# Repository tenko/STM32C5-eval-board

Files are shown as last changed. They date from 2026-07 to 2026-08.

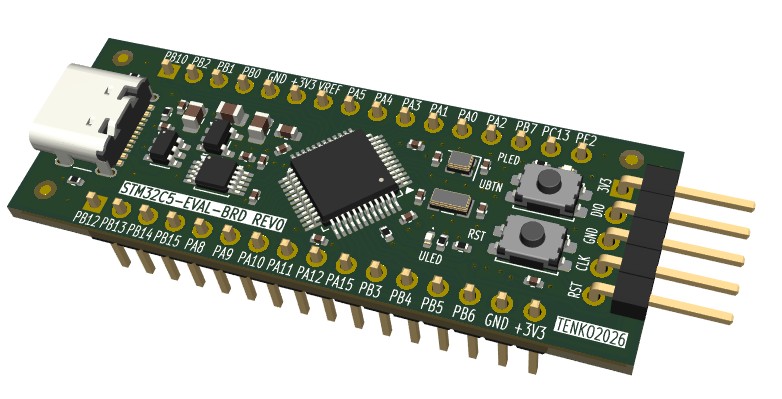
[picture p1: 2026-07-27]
fab/stm32c5-evaluation-board-3d.jpg

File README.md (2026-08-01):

# STM32C5-eval-board

Custom *STM32C5* board in the breadboard friendly *BluePill* format designed in *Kicad v10*.

**Features**

- Compact breadboard friendly board size at 53.5mm x 20mm with 2x16 pin headers.
- STM32C551CE Cortex-M33 MCU, 144 MHz, 512 KB flash, 128 KB RAM. ([Product page](https://www.st.com/en/microcontrollers-microprocessors/stm32c551ce.html) / [Datasheet](https://www.st.com/resource/en/datasheet/stm32c551ce.pdf))
- USB-C power connection with CH340E uart to usb bridge (USART1 used).
- LSE 32768 Hz crystal and HSE with 24 MHz crystal.
- 3V3 LDO with power status led.
- Reset button.
- User led and user button.
- SWD header for programming (Must be used as BOOT0 is not exposed).
- All other MCU pins is routed to board edge headers.

**Note** 

This MCU family is quite new and therefore not all variants of this MCU was available with the usual suppliers
when this board was created. When other variants with *LQFP-48* footprints is available this should be pin compatible
with the layout of this board.

**Pinout** 
stm32c5-evaluation-board-pinout

For complete pin alternative function definitions it is recommended to use the *STMicroelectronics* application *CubeMX2*.

**Production**

Production files adapted to [PCBWay](https://www.pcbway.com/) recommendations is found in the *fab* folder.

**Firmware**

As this is a new MCU family I could only get the *STMicroelectronics* original software
and hardware to work with flashing the device. *SEGGER's J-Link* Debug Probe will also
probably support this MCU family.

In the *firmware* folder there is a project file for *CubeMX2*. By opening this file
it as matter of generate the *CMake* project files.

I used *VSCode* and the *CubeMX* extension to open the generated *CMake* project files and
added the following test code for a simple blinker application:

```C++
/*
  * You can start your application code here
  */

while (1) {
  printf("hello!\n");
  HAL_GPIO_TogglePin(HAL_GPIOB, HAL_GPIO_PIN_9);
  HAL_Delay(2000);
}
```

**Alternative Firmware in Oberon-2**

As an alternative to *C/C++* the [ECSOberon](https://ecs.openbrace.org/) language and the
[ECSMicroLib](https://github.com/tenko/ECSMicroLib/) framework can be used to develop
firmware for this board.

*ECSOberon* has a number of benefits for MCU applications:

- Simplest possible language (the [language report](https://github.com/OberonSystem3/TheOberonCompanionCD/blob/main/Papers/Oberon2.pdf?raw=true) is 20 pages), yet supporting 
  object oriented design with single inheritance.
- The language has the bit *SET* type which makes fiddling with bit register of the *MCU* very easy and natural.
- The *ECSOberon* language is updated with manual allocation, unsigned types, variable pointers, packages and simple templates.
  Making the language more practical for system programming and *MCUs* than the original *Oberon-2* implementation.
- No header files to worry about. The visibility of the code elements is defined directly in the module.
- The module and package concept keeps the code cleanly segregated and avoid the problem with colliding names in *C*.
- The [documentation](https://ecs.openbrace.org/manual/) is excellent and reported bugs is fixed quickly.

The drawbacks of *ECSOberon*:

- *Oberon-2* is a verbose language and require upper case keyword.
  However with an *IDE* and auto-completion this is a minor issue in my opinion.
- No support for a pre-processor. Some cases can be solved with help of templates, but otherwise
  this must be solved with shell scripts.
  However this omission keeps the code base readable in my opinion.
- Not much existing code exists and many things must be implemented from scratch.
  Code from the original [OberonSystem 3](https://github.com/OberonSystem3) or from [BlackBox Component Builder](https://blackbox.oberon.org/) could be reused.
  
  This is the major drawback in my opinion.

**Testing**

[board-testing.webm](https://github.com/user-attachments/assets/a6211ade-eac5-4887-8b39-223c8f42b538)

The board has been verified to work correctly with the uart-to-usb bridge, leds, buttons and crystals.

Minor issues:

- The *SWDIO* and *SWDCLK* pin was swapped.
- The silkscreen was difficult to read.

This will be fixed in a future revision along with any other issue.

**TODO** 

- Fix *SWD CLK/DIO* swap on silkscreen and schematic.
- Possible expose *BOOT0* with a test point on PCB.
- Possible add PCB jumper to disconnect power led for battery operations.
- Review pins used for user button/led and usb-to-uart.

**Sponsors** 

This board was generously sponsored by [PCBWay](https://www.pcbway.com/) and this project was handled
in quick and professional way in my experience. Thanks.

**Acknowledgments**

This board was developed and with help of and inspiration by the excellent instruction videos on the [Phil's Lab](https://www.youtube.com/@PhilsLab)
Youtube channel.

Also initially skeptical to *KiCAD* software, it turned out to be a very nice experience working with this application.
The team behind *KiCAD* does an excellent job in turning this application into a professional tool.

## License
This project is licensed under the MIT License - see the LICENSE file for details.

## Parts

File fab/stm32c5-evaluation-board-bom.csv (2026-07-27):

Item # | Designator | Qty | Manufacturer | Mfg Part # | Description | Value | Footprint | Datasheet | Distributor Link 1 | Distributor Link 2
1 | C1,C2,C4,C6,C7,C8,C10,C11,C13,C14 | 10 | Murata Electronics | GRM155R71E104KE14D | Unpolarized capacitor MLCC X7R | 100n | Capacitor_SMD:C_0402_1005Metric | https://search.murata.co.jp/Ceramy/image/img/A01X/G101/ENG/GRM155R71E104KE14-01.pdf | https://eu.mouser.com/ProductDetail/Murata-Electronics/GRM155R71E104KE14D?qs=IPQhFcwEUOgaz7Co1ZLU6w%3D%3D | https://www.digikey.com/en/products/detail/murata-electronics/GRM155R71E104KE14D/4905173
2 | C3,C5,C9 | 3 | Murata Electronics | GRM21BZ71E475KE15L | Unpolarized capacitor MLCC X7R | 4u7 | Capacitor_SMD:C_0805_2012Metric | https://search.murata.co.jp/Ceramy/image/img/A01X/G101/ENG/GRM21BZ71E475KE15-01.pdf | https://eu.mouser.com/ProductDetail/Murata-Electronics/GRM21BZ71E475KE15L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 | https://www.digikey.com/en/products/detail/murata-electronics/GRM21BZ71E475KE15L/13904861
3 | C12 | 1 | Murata Electronics | GRM188Z71E225KE43D | Unpolarized capacitor MLCC X7R | 2u2 | Capacitor_SMD:C_0603_1608Metric | https://pim.murata.com/asset/pim4/ceramicCapacitorSMD/GRM188Z71E225KE43-01A-EN_PDF_CERAMICCAPACITORSMD | https://eu.mouser.com/ProductDetail/Murata-Electronics/GRM188Z71E225KE43D?qs=Ey7%2FXF42M3cRXEZQV5QZIQ%3D%3D | https://www.digikey.com/en/products/detail/murata-electronics/GRM188Z71E225KE43D/16602147
4 | C15,C16 | 2 | Murata Electronics | GCM1555C1H6R0BA16D | Unpolarized capacitor MLCC NP0 | 6p | Capacitor_SMD:C_0402_1005Metric | https://eu.mouser.com/datasheet/3/76/3/GCM1555C1H6R0BA16_01A.pdf | https://eu.mouser.com/ProductDetail/Murata-Electronics/GCM1555C1H6R0BA16D?qs=QzBtWTOodeXySBgacy71QA%3D%3D | https://www.digikey.com/en/products/detail/murata-electronics/GCM1555C1H6R0BA16D/11618627
5 | C17,C18 | 2 | Murata Electronics | GCM1555C1H200FA16D | Unpolarized capacitor MLCC NP0 | 20p | Capacitor_SMD:C_0402_1005Metric | https://pim.murata.com/asset/pim4/ceramicCapacitorSMD/GCM1555C1H200FA16-01A-EN_PDF_CERAMICCAPACITORSMD | https://eu.mouser.com/ProductDetail/Murata-Electronics/GCM1555C1H200FA16D?qs=QzBtWTOodeWP0i4OUEdl4Q%3D%3D | https://www.digikey.com/en/products/detail/murata-electronics/GCM1555C1H200FA16D/13401847
6 | D1 | 1 | STMicroelectronics | USBLC6-2SC6 | Very low capacitance ESD protection diode, 2 data-line, SOT-23-6 | USBLC6-2SC6 | Package_TO_SOT_SMD:SOT-23-6 | https://www.st.com/resource/en/datasheet/usblc6-2.pdf | https://www.digikey.com/en/products/detail/stmicroelectronics/USBLC6-2SC6/1040559 | https://eu.mouser.com/ProductDetail/STMicroelectronics/USBLC6-2SC6?qs=po45yt2pPpu%2FhNIlwQdTlg%3D%3D
7 | D2 | 1 | Wurth Elektronik | 150040VS73240 | Light emitting diode green | GR | LED_SMD:LED_0402_1005Metric | https://www.we-online.com/components/products/datasheet/150040VS73240.pdf | https://eu.mouser.com/ProductDetail/Wurth-Elektronik/150040VS73240?qs=8Aam6%252B7C6HEhyesRm%252BQyFQ%3D%3D | https://www.digikey.com/en/products/detail/w%C3%BCrth-elektronik/150040VS73240/8557157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
8 | D3 | 1 | Wurth Elektronik | 150040RS73240 | Light emitting diode | RD | LED_SMD:LED_0402_1005Metric | https://www.we-online.com/components/products/datasheet/150040RS73240.pdf | https://eu.mouser.com/ProductDetail/Wurth-Elektronik/150040RS73240?qs=8Aam6%252B7C6HGMiInmnlrBiw%3D%3D | https://www.digikey.com/en/products/detail/w%C3%BCrth-elektronik/150040RS73240/8557156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
9 | J1 | 1 | Global Connector Technology | USB4105-GF-A-120 | USB 2.0-only 16P Type-C Receptacle connector | USB4105-GF-A | Connector_USB:USB_C_Receptacle_GCT_USB4105-xx-A_16P_TopMnt_Horizontal | https://www.mouser.com/catalog/specsheets/Global_Connector_Technology_usb4105.pdf | https://eu.mouser.com/ProductDetail/GCT/USB4105-GF-A-120?qs=QNEnbhJQKva%252Bjxw%2FpEjDhQ%3D%3D | https://www.digikey.com/en/products/detail/gct/USB4105-GF-A-120/14559037
10 | R1,R2 | 2 | YAGEO | RC0402FR-075K1L | Resistor | 5k1 | Resistor_SMD:R_0402_1005Metric | https://www.mouser.com/catalog/specsheets/YAGEO_PYu_RC_Group_51_RoHS_L_12.pdf | https://eu.mouser.com/ProductDetail/YAGEO/RC0402FR-075K1L?qs=YUgVZYePFqCSmQuaha43RA%3D%3D | https://www.digikey.com/en/products/detail/yageo/RC0402FR-075K1L/726624
11 | R3 | 1 | YAGEO | RC0402FR-070RL | Resistor | 0R | Resistor_SMD:R_0402_1005Metric | https://www.mouser.com/catalog/specsheets/YAGEO_PYu_RC_Group_51_RoHS_L_12.pdf | https://eu.mouser.com/ProductDetail/YAGEO/RC0402FR-070RL?qs=sxZXDnvRBEhfSy4CZGX2ww%3D%3D | https://www.digikey.com/en/products/detail/yageo/RC0402FR-070RL/2827570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
12 | R4,R8 | 2 | YAGEO | RC0402FR-07220RL | Resistor | 220R | Resistor_SMD:R_0402_1005Metric | https://www.mouser.com/catalog/specsheets/YAGEO_PYu_RC_Group_51_RoHS_L_12.pdf | https://eu.mouser.com/ProductDetail/YAGEO/RC0402FR-07220RL?qs=UOUeRUa%252B8Wkw9iNOZEwgHw%3D%3D | https://www.digikey.com/en/products/detail/yageo/RC0402FR-07220RL/726565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
13 | R5,R6 | 2 | YAGEO | RC0402FR-0710KL | Resistor | 10k | Resistor_SMD:R_0402_1005Metric | https://www.mouser.com/catalog/specsheets/YAGEO_PYu_RC_Group_51_RoHS_L_12.pdf | https://eu.mouser.com/ProductDetail/YAGEO/RC0402FR-0710KL?qs=I1mnnYJTTsxUoNwrUsQExA%3D%3D | https://www.digikey.com/en/products/detail/yageo/RC0402FR-0710KL/726523
14 | SW1,SW2 | 2 | Panasonic | EVQ-P2K02Q | Tactile Switches NO SPST 4.7mm x 3.5mm | EVQ-P2K02Q | Button_Switch_SMD:SW_SPST_EVQP2_MiddlePushTravel_H2.5mm | https://4donline.ihs.com/images/VipMasterIC/IC/PANA/PANAS38695/PANAS38695-1.pdf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 | https://eu.mouser.com/ProductDetail/Panasonic/EVQ-P2K02Q?qs=whhzBCqEXCsdBl5GlK3V%252BA%3D%3D | https://www.digikey.com/en/products/detail/panasonic-industry/EVQ-P2K02Q/304155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
15 | U1 | 1 | MaxLinear, Inc. | SPX3819M5-L-3-3 | 500mA Low drop-out regulator, Fixed Output 3.3V, SOT-23-5 | SPX3819M5-L-3-3 | Package_TO_SOT_SMD:SOT-23-5 | https://www.maxlinear.com/Document/index?id=22106&languageid=1033&type=Data%20Sheets&partnumber=SPX3819 | https://www.digikey.com/en/products/detail/maxlinear-inc/SPX3819M5-L-3-3/2411180 | https://eu.mouser.com/ProductDetail/MaxLinear/SPX3819M5-L-3-3-TR?qs=S%2FCBhQS5rCp1Bb7a%252BD%2FCBQ%3D%3D
16 | U2 | 1 | WCH | CH340E | USB serial converter, UART, MSOP-10 | CH340E | Package_SO:MSOP-10_3x3mm_P0.5mm | https://www.mpja.com/download/35227cpdata.pdf | https://www.lcsc.com/product-detail/C99652.html
17 | U3 | 1 | STMicroelectronics | STM32C551CET6 | Microcontroller ARM Cortex-M33 144MHz 512kB 128kB | STM32C551CET6 | Package_QFP:LQFP-48_7x7mm_P0.5mm | https://www.st.com/resource/en/datasheet/stm32c551ce.pdf | https://eu.mouser.com/ProductDetail/STMicroelectronics/STM32C551CET6?qs=6avfeC6zeS7PMoCK0lCKwQ%3D%3D | https://www.digikey.com/en/products/detail/stmicroelectronics/STM32C551CET6/29220411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
18 | X1 | 1 | KYOCERA AVX | CX2016FB24000B0FZZH1 | Four pin crystal, GND on pins 2 and 4 | 24MHz | Crystal:Crystal_SMD_2016-4Pin_2.0x1.6mm | https://ele.kyocera.com/assets/products/crystal-device/specification/CX2016FB_6pF.pdf | https://eu.mouser.com/ProductDetail/KYOCERA-AVX/CX2016FB24000B0FZZH1?qs=Tc%252BHE9vUsnuCDMqNTSZCqQ%3D%3D | https://www.digikey.com/en/products/detail/kyocera-avx/CX2016FB24000B0FZZH1/28376742
19 | X2 | 1 | Epson | FC-135 32.7680KA-A3 | Two pin crystal | 32kHz768 | stm32c5-evaluation-board-footprints:Crystal_SMD_3215-2Pin_3.2x1.5mm | https://download.epsondevice.com/td/pdf/brief/FC-135_en.pdf | https://eu.mouser.com/ProductDetail/Epson-Timing/FC-135R-32.7680KA-A3?qs=f9yNj16SXrIR19rZDPQCyw%3D%3D | https://www.digikey.com/en/products/detail/epson/FC-135-32-7680KA-A3/569818

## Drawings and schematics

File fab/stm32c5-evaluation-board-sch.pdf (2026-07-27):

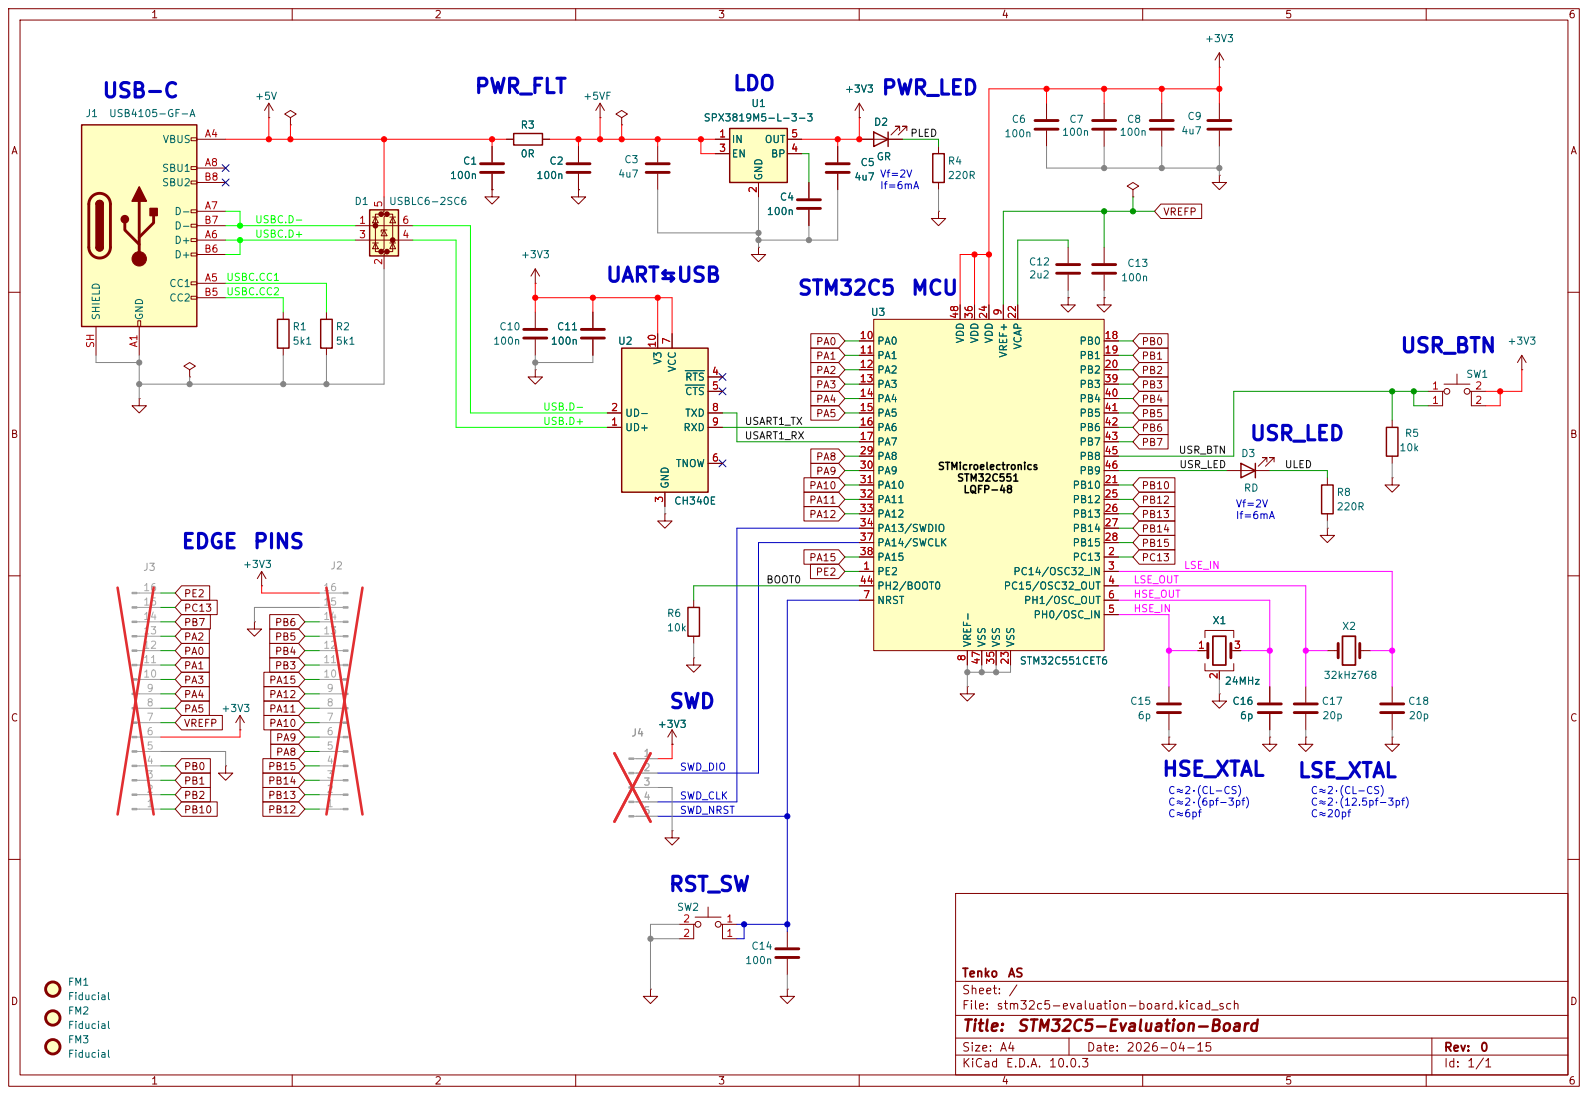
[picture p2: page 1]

9 PA0 10 PA1 11 PA2 12 PA3 13 PA4 14 PA5 15 PA6 16 PA7 17 PB0 18 PB1 19 PB2 20 PB10 21 VSS 23 VDD 24 PB12 25 PB13 26 PB14 27 PB15 28 PA8 29 PA9 30 PA10 31 PA11 32 PA12 33 PA13/SWDIO 34 VSS 35 VDD 36

Size: A4 | Rev: 0
KiCad E.D.A. 10.0.3 | Id: 1/1

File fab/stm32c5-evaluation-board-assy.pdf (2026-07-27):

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

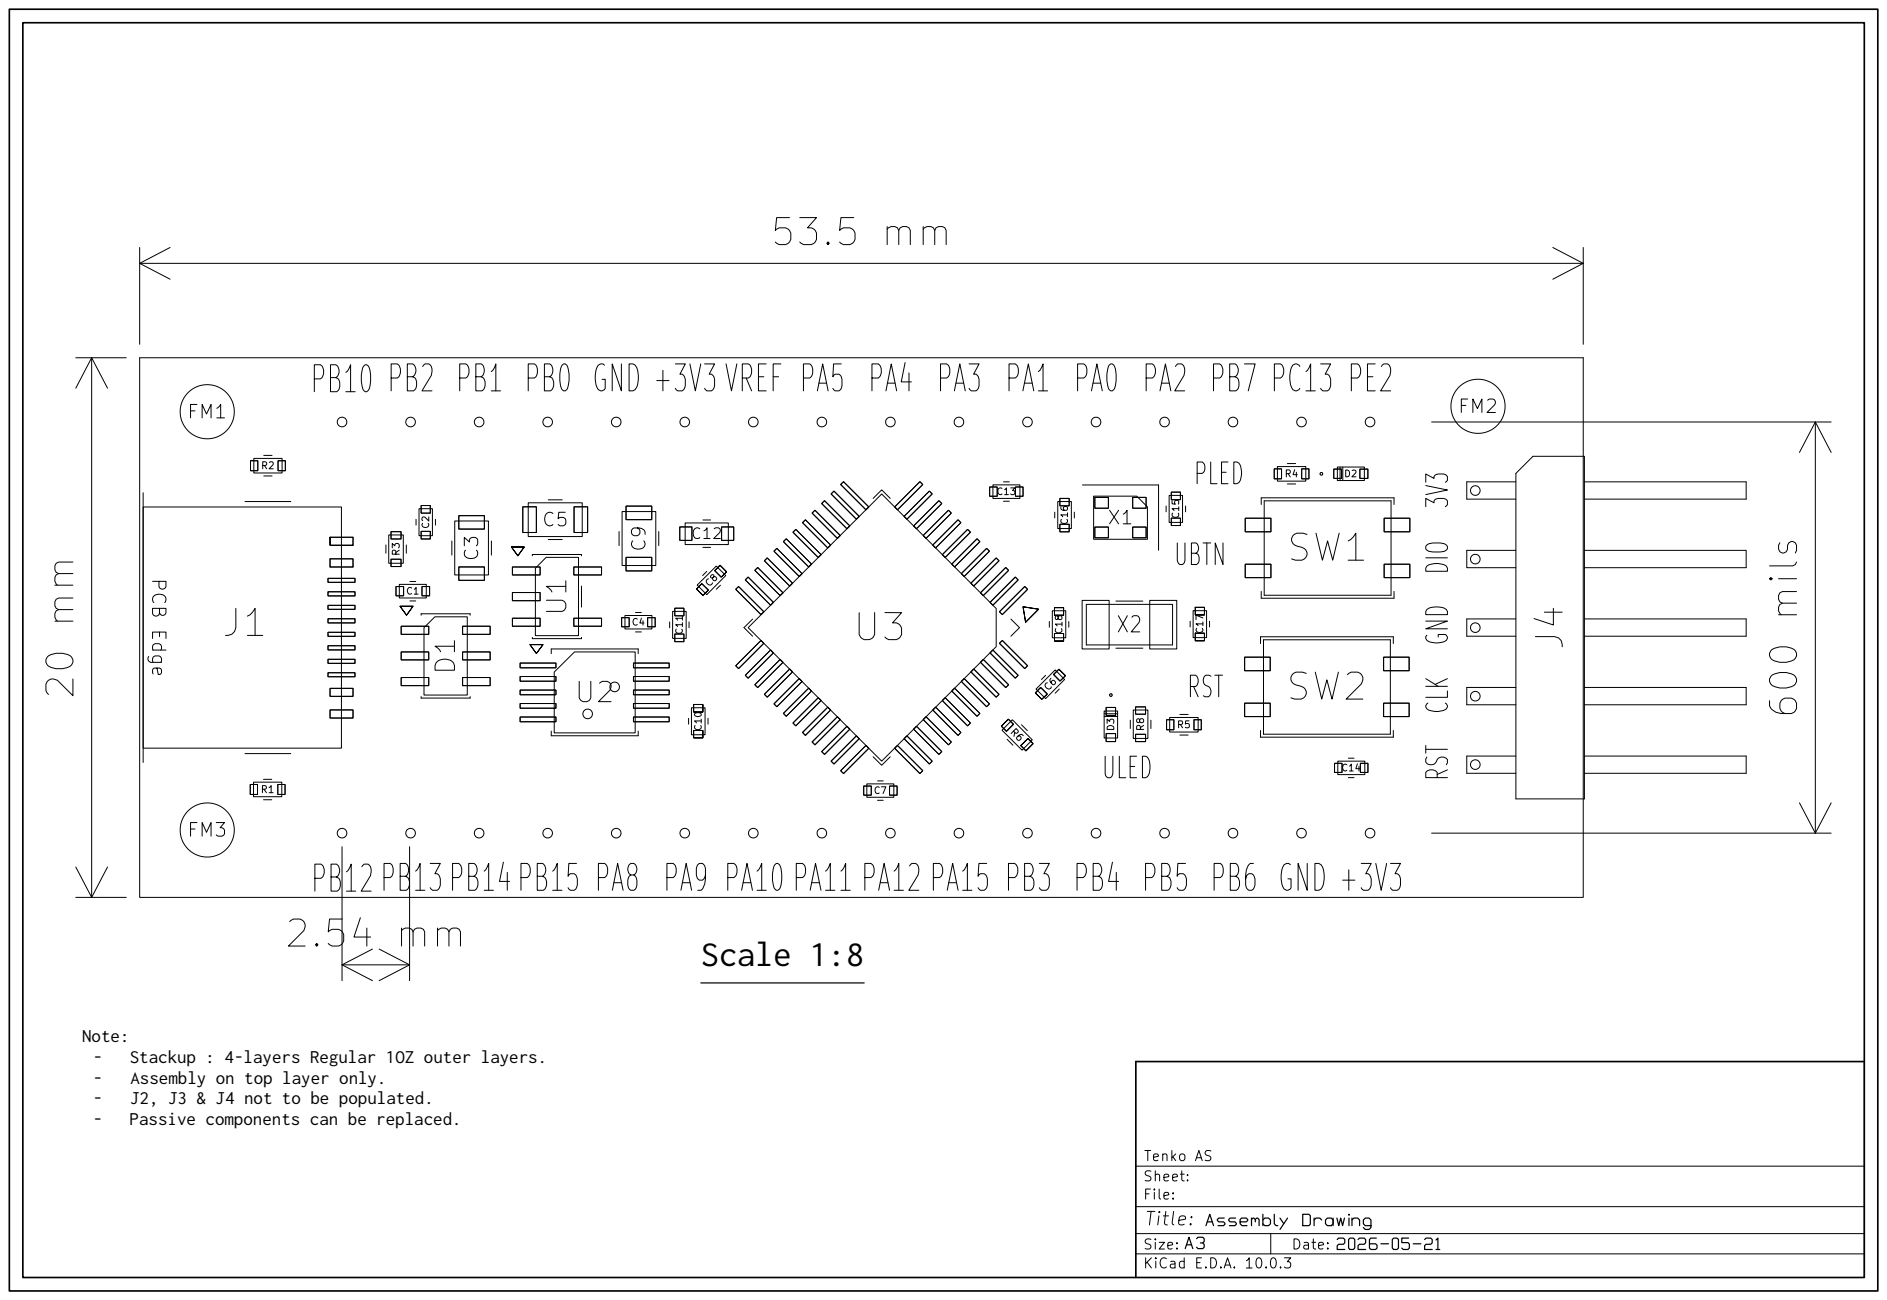
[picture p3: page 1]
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

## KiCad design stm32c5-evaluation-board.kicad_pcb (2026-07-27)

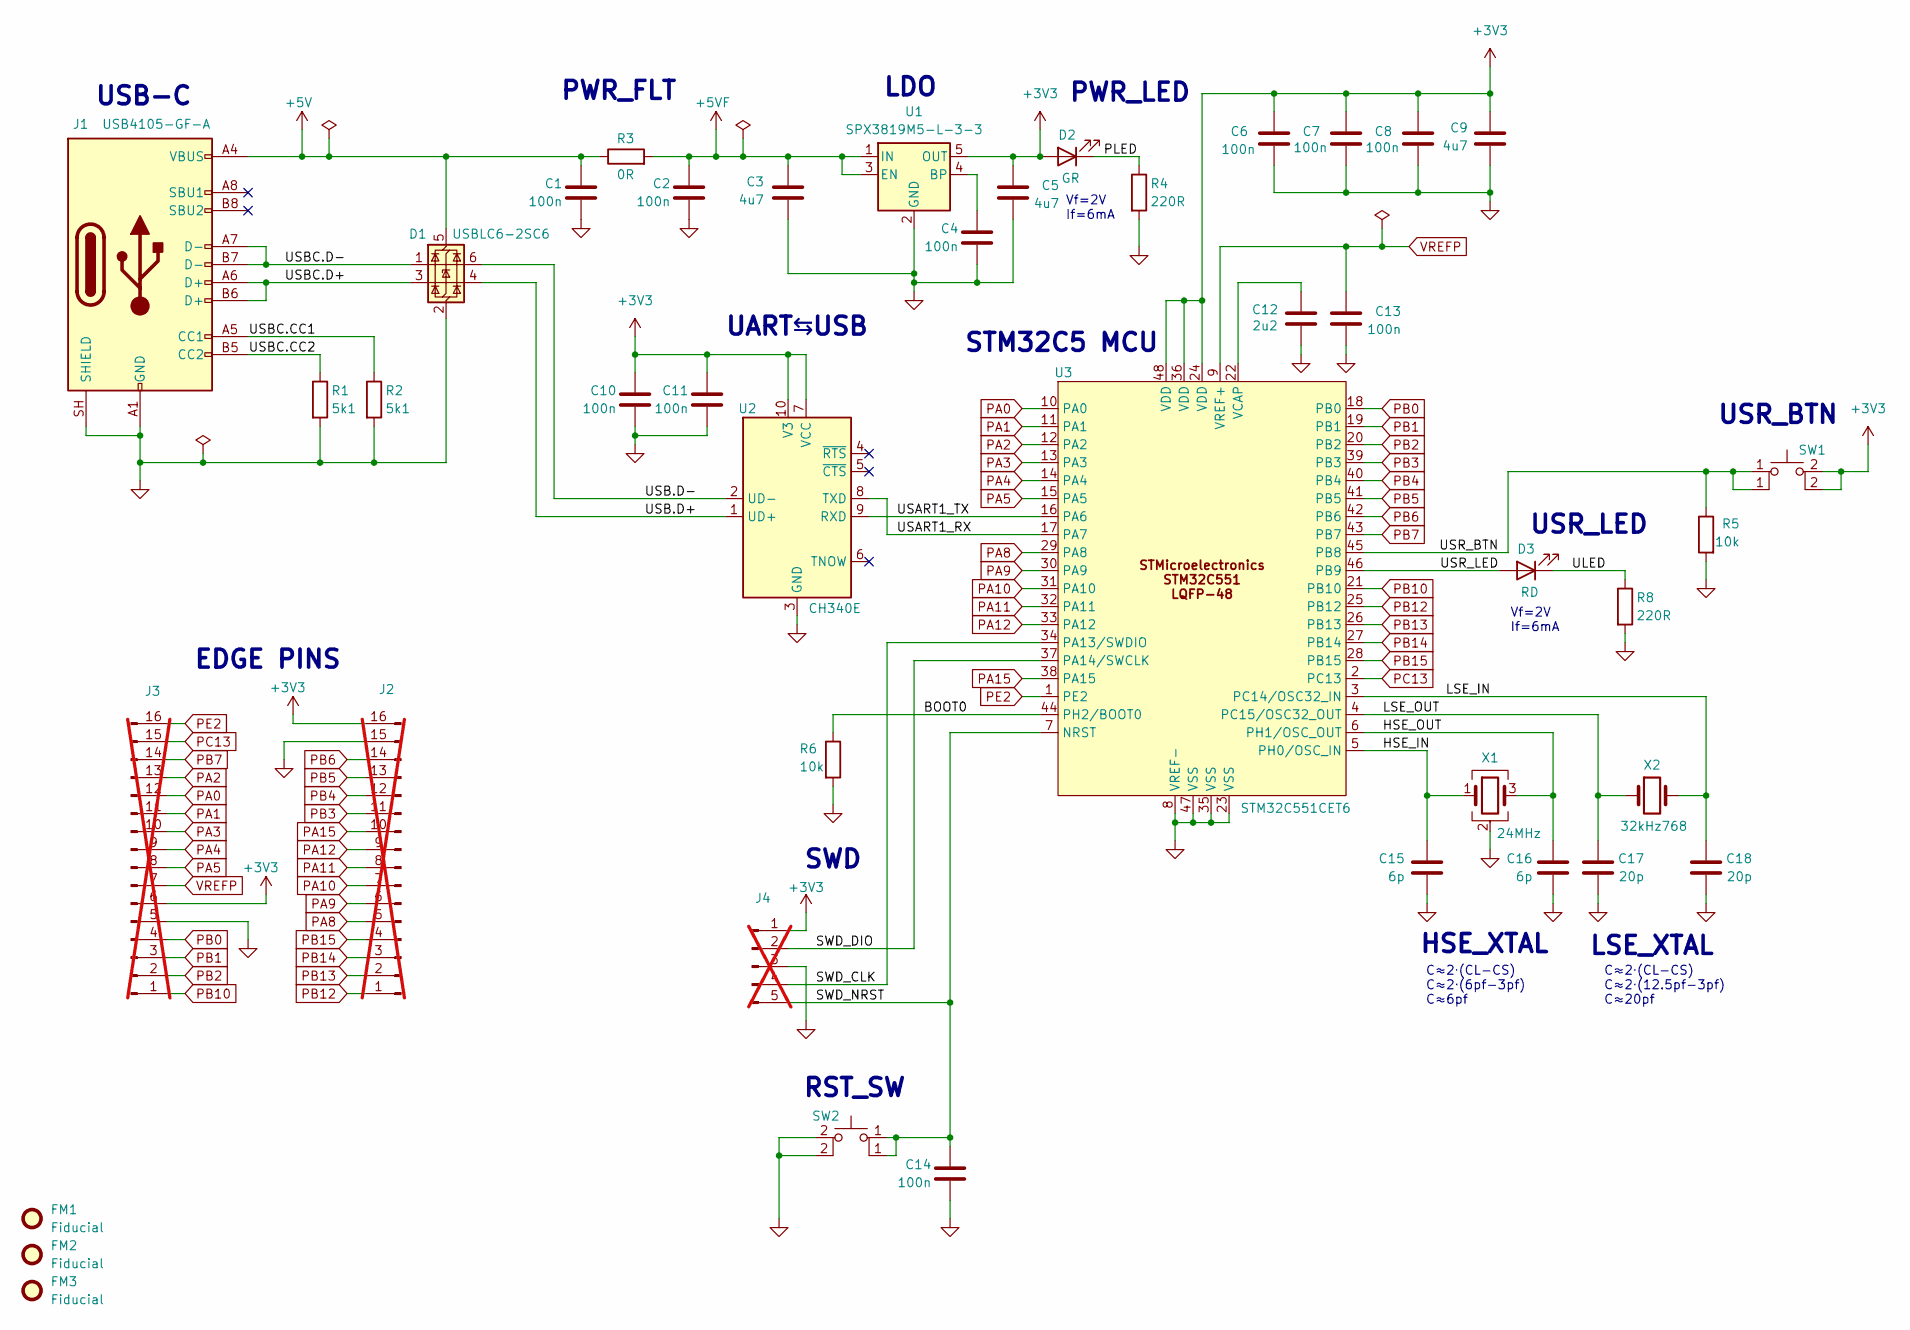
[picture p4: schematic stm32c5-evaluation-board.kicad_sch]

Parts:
C1, C2, C4, C6, C7, C8, C10, C11, C13, C14: 100n; C_0402_1005Metric; Manufacturer Part Number GRM155R71E104KE14D
C3, C5, C9: 4u7; C_0805_2012Metric; Manufacturer Part Number GRM21BZ71E475KE15L
C12: 2u2; C_0603_1608Metric; Manufacturer Part Number GRM188Z71E225KE43D
C15, C16: 6p; C_0402_1005Metric; Manufacturer Part Number GCM1555C1H6R0BA16D
C17, C18: 20p; C_0402_1005Metric; Manufacturer Part Number GCM1555C1H200FA16D
D1: USBLC6-2SC6; SOT-23-6; Manufacturer Part Number USBLC6-2SC6
D2: GR; LED_0402_1005Metric; Manufacturer Part Number 150040VS73240
D3: RD; LED_0402_1005Metric; Manufacturer Part Number 150040RS73240
FM1, FM2, FM3: Fiducial; Fiducial_1mm_Mask2mm
J1: USB4105-GF-A; USB_C_Receptacle_GCT_USB4105-xx-A_16P_TopMnt_Horizontal; Manufacturer Part Number USB4105-GF-A-120
J2, J3: Conn_01x16_Pin; PinHeader_1x16_P2.54mm_Vertical; not fitted
J4: Conn_01x05_Pin; PinHeader_1x05_P2.54mm_Horizontal; not fitted
R1, R2: 5k1; R_0402_1005Metric; Manufacturer Part Number RC0402FR-075K1L
R3: 0R; R_0402_1005Metric; Manufacturer Part Number RC0402FR-070RL
R4, R8: 220R; R_0402_1005Metric; Manufacturer Part Number RC0402FR-07220RL
R5, R6: 10k; R_0402_1005Metric; Manufacturer Part Number RC0402FR-0710KL
SW1, SW2: EVQ-P2K02Q; SW_SPST_EVQP2_MiddlePushTravel_H2.5mm; Manufacturer Part Number EVQ-P2K02Q
U1: SPX3819M5-L-3-3; SOT-23-5; Manufacturer Part Number SPX3819M5-L-3-3
U2: CH340E; MSOP-10_3x3mm_P0.5mm; Manufacturer Part Number CH340E
U3: STM32C551CET6; LQFP-48_7x7mm_P0.5mm; Manufacturer Part Number STM32C551CET6
X1: 24MHz; Crystal_SMD_2016-4Pin_2.0x1.6mm; Manufacturer Part Number CX2016FB24000B0FZZH1
X2: 32kHz768; Crystal_SMD_3215-2Pin_3.2x1.5mm; Manufacturer Part Number FC-135 32.7680KA-A3

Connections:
+3V3: C5.1, C6.1, C7.1, C8.1, C9.1, C10.1, C11.1, D2.2 (A), J2.16, J3.6, J4.1, SW1.2 (C), U1.5 (OUT), U2.7 (VCC), U2.10 (V3), U3.24 (VDD), U3.36 (VDD), U3.48 (VDD)
+5V: C1.1, D1.5 (VBUS), J1.A4 (VBUS), J1.A9 (VBUS), J1.B4 (VBUS), J1.B9 (VBUS), R3.1
+5VF: C2.1, C3.1, R3.2, U1.1 (IN), U1.3 (EN)
/BOOT0: R6.1, U3.44 (PH2/BOOT0)
/HSE_IN: C15.1, U3.5 (PH0/OSC_IN), X1.1
/HSE_OUT: C16.1, U3.6 (PH1/OSC_OUT), X1.3
/LSE_IN: C18.1, U3.3 (PC14/OSC32_IN), X2.2
/LSE_OUT: C17.1, U3.4 (PC15/OSC32_OUT), X2.1
/PLED: D2.1 (K), R4.1
/SWD_CLK: J4.4, U3.34 (PA13/SWDIO)
/SWD_DIO: J4.2, U3.37 (PA14/SWCLK)
/SWD_NRST: C14.1, J4.5, SW2.1 (A), U3.7 (NRST)
/ULED: D3.1 (K), R8.1
/USART1_RX: U2.8 (TXD), U3.17 (PA7)
/USART1_TX: U2.9 (RXD), U3.16 (PA6)
/USB.D+: D1.4 (I/O2), U2.1 (UD+)
/USB.D-: D1.6 (I/O1), U2.2 (UD-)
/USBC.CC1: J1.A5 (CC1), R2.1
/USBC.CC2: J1.B5 (CC2), R1.1
/USBC.D+: D1.3 (I/O2), J1.A6 (D+), J1.B6 (D+)
/USBC.D-: D1.1 (I/O1), J1.A7 (D-), J1.B7 (D-)
/USR_BTN: R5.1, SW1.1 (A), U3.45 (PB8)
/USR_LED: D3.2 (A), U3.46 (PB9)
GND: C1.2, C2.2, C3.2, C4.2, C5.2, C6.2, C7.2, C8.2, C9.2, C10.2, C11.2, C12.1, C13.2, C14.2, C15.2, C16.2, C17.2, C18.2, D1.2 (GND), J1.A1 (GND), J1.A12 (GND), J1.B1 (GND), J1.B12 (GND), J1.SH (SHIELD), J2.15, J3.5, J4.3, R1.2, R2.2, R4.2, R5.2, R6.2, R8.2, SW2.2 (D), U1.2 (GND), U2.3 (GND), U3.8 (VREF-), U3.23 (VSS), U3.35 (VSS), U3.47 (VSS), X1.2 (G), X1.4 (G)
unnamed: C4.1, U1.4 (BP)
unnamed: C12.2, U3.22 (VCAP)
PA0: J3.12, U3.10 (PA0)
PA1: J3.11, U3.11 (PA1)
PA2: J3.13, U3.12 (PA2)
PA3: J3.10, U3.13 (PA3)
PA4: J3.9, U3.14 (PA4)
PA5: J3.8, U3.15 (PA5)
PA8: J2.5, U3.29 (PA8)
PA9: J2.6, U3.30 (PA9)
PA10: J2.7, U3.31 (PA10)
PA11: J2.8, U3.32 (PA11)
PA12: J2.9, U3.33 (PA12)
PA15: J2.10, U3.38 (PA15)
PB0: J3.4, U3.18 (PB0)
PB1: J3.3, U3.19 (PB1)
PB2: J3.2, U3.20 (PB2)
PB3: J2.11, U3.39 (PB3)
PB4: J2.12, U3.40 (PB4)
PB5: J2.13, U3.41 (PB5)
PB6: J2.14, U3.42 (PB6)
PB7: J3.14, U3.43 (PB7)
PB10: J3.1, U3.21 (PB10)
PB12: J2.1, U3.25 (PB12)
PB13: J2.2, U3.26 (PB13)
PB14: J2.3, U3.27 (PB14)
PB15: J2.4, U3.28 (PB15)
PC13: J3.15, U3.2 (PC13)
PE2: J3.16, U3.1 (PE2)
VREFP: C13.1, J3.7, U3.9 (VREF+)

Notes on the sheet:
SWD
USR_LED
USB-C
EDGE PINS
PWR_FLT
STM32C5 MCU
RST_SW
USR_BTN
Vf=2V If=6mA
UART⇆USB
C≈2⋅(CL-CS) C≈2⋅(12.5pf-3pf) C≈20pf
LSE_XTAL
LDO
HSE_XTAL
C≈2⋅(CL-CS) C≈2⋅(6pf-3pf) C≈6pf
PWR_LED

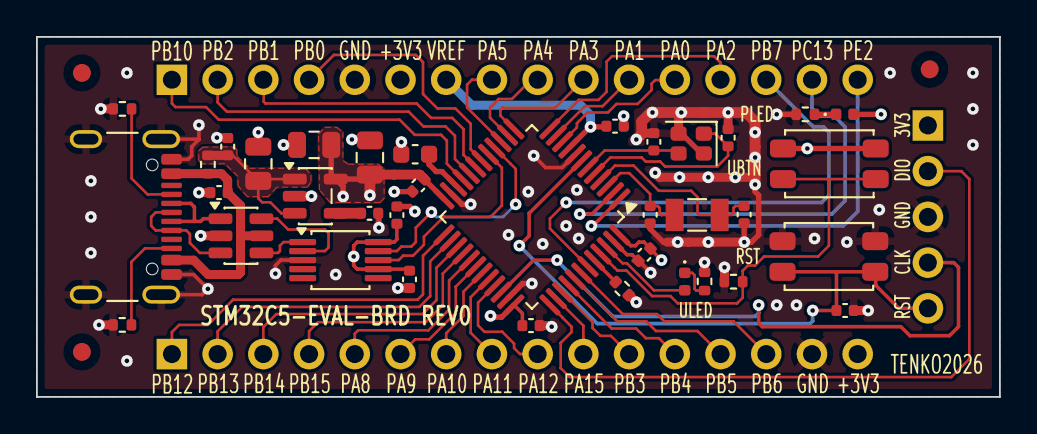
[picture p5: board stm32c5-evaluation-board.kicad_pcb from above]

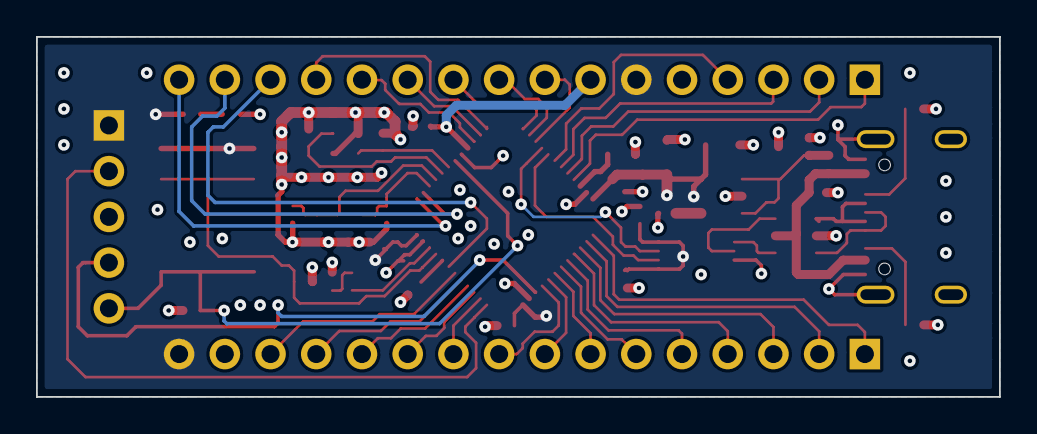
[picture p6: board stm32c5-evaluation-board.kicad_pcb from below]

Board: 4 copper layers, 53.5 x 20.0 mm, 42 parts (2 on the bottom side), 54 nets.

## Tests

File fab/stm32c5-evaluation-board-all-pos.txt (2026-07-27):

### Footprint positions - created on 2026-05-21T19:56:50 ###
### Printed by KiCad version 10.0.3
## Unit = mm, Angle = deg.
## Side : All
# Ref     Val              Package                                                       PosX       PosY       Rot  Side
J2        Conn_01x16_Pin   PinHeader_1x16_P2.54mm_Vertical                             7.5000     2.3800  -90.0000  bottom
J3        Conn_01x16_Pin   PinHeader_1x16_P2.54mm_Vertical                             7.5000    17.6200  -90.0000  bottom
C1        100n             C_0402_1005Metric                                          10.1200    11.3500  180.0000  top
C2        100n             C_0402_1005Metric                                          10.6000    13.9050   90.0000  top
C3        4u7              C_0805_2012Metric                                          12.3000    12.9500   90.0000  top
C4        100n             C_0402_1005Metric                                          18.4825    10.2000    0.0000  top
C5        4u7              C_0805_2012Metric                                          15.4000    14.0000  180.0000  top
C6        100n             C_0402_1005Metric                                          33.7500     7.9000  -135.0000  top
C7        100n             C_0402_1005Metric                                          27.4500     3.9600    0.0000  top
C8        100n             C_0402_1005Metric                                          21.1906    11.7506  -135.0000  top
C9        4u7              C_0805_2012Metric                                          18.5000    13.3000   90.0000  top
C10       100n             C_0402_1005Metric                                          20.7000     6.5300  -90.0000  top
C11       100n             C_0402_1005Metric                                          20.0000    10.1000   90.0000  top
C12       2u2              C_0603_1608Metric                                          21.0150    13.4800    0.0000  top
C13       100n             C_0402_1005Metric                                          32.1194    15.0394    0.0000  top
C14       100n             C_0402_1005Metric                                          44.9000     4.8000    0.0000  top
C15       6p               C_0402_1005Metric                                          38.4000    14.4000   90.0000  top
C16       6p               C_0402_1005Metric                                          34.2750    14.1700   90.0000  top
C17       20p              C_0402_1005Metric                                          39.2900    10.1300  -90.0000  top
C18       20p              C_0402_1005Metric                                          34.0700    10.1200  -90.0000  top
D1        USBLC6-2SC6      SOT-23-6                                                   11.3375     8.9500    0.0000  top
D2        GR               LED_0402_1005Metric                                        44.8850    15.7000    0.0000  top
D3        RD               LED_0402_1005Metric                                        35.9925     6.4075  -90.0000  top
J1        USB4105-GF-A     USB_C_Receptacle_GCT_USB4105-xx-A_16P_TopMnt_Horizontal     3.8000    10.0000  -90.0000  top
J4        Conn_01x05_Pin   PinHeader_1x05_P2.54mm_Horizontal                          49.5000    15.0800    0.0000  top
R1        5k1              R_0402_1005Metric                                           4.7400     4.0000  180.0000  top
R2        5k1              R_0402_1005Metric                                           4.7500    16.0000  180.0000  top
R3        0R               R_0402_1005Metric                                           9.5000    12.9100   90.0000  top
R4        220R             R_0402_1005Metric                                          42.6900    15.7000  180.0000  top
R5        10k              R_0402_1005Metric                                          38.7000     6.4000  180.0000  top
R6        10k              R_0402_1005Metric                                          32.5200     6.0200  -45.0000  top
R8        220R             R_0402_1005Metric                                          37.0925     6.4175   90.0000  top
SW1       EVQ-P2K02Q       SW_SPST_EVQP2_MiddlePushTravel_H2.5mm                      44.0250    12.9500  180.0000  top
SW2       EVQ-P2K02Q       SW_SPST_EVQP2_MiddlePushTravel_H2.5mm                      44.0000     7.8000  180.0000  top
U1        SPX3819M5-L-3-3  SOT-23-5                                                   15.4625    11.1500    0.0000  top
U2        CH340E           MSOP-10_3x3mm_P0.5mm                                       16.8625     7.6000    0.0000  top
U3        STM32C551CET6    LQFP-48_7x7mm_P0.5mm                                       27.5000    10.0000  -135.0000  top
X1        24MHz            Crystal_SMD_2016-4Pin_2.0x1.6mm                            36.3500    14.0750  180.0000  top
X2        32kHz768         Crystal_SMD_3215-2Pin_3.2x1.5mm                            36.6800    10.1100    0.0000  top
## End
